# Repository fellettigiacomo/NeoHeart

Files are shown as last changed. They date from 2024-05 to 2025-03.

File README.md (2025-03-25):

# NeoHeart - Revision 2.2🎉
Hardware and Software design for an Open Source ATtiny816-based heart shaped PCB with Addressable LEDs.
<br><br>board-render
## Project sponsor: PCBWay
Thanks to [PCBWay](https://www.pcbway.com/) for sponsoring this open-source project. Check out the sponsorship section below to learn more about their support.

## Features

- **Microcontroller**: ATtiny816
- **LEDs**: 25 SK6805-MINIJ Addressable RGB LEDs
- **Power**: 3V CR2032 battery
- **Programming**: UPDI programming interface
- **Software**: Built using Adafruit's Neopixel library, featuring 10 built-in animations and efficient power management
- **Additional Features**:
  - Low current consumption design
  - Integrated MOSFET for powering down LEDs to save power
  - Additional digital/analog exposed GPIO to hack your NeoHeart in unexpected ways
  
## 2.2 Upgrades

- **Efficient power design**: the TPS61240 boost converter has been fully redesigned—now controlled by the MCU via the Enable pin (no more external MOSFET). Improved input stability with additional capacitors, removed feedback resistors for better overall efficiency.
- **Extended Battery Life**: ultra-low 0.14 µA quiescent current enables over 10 years of idle operation and supports 1000+ button presses on a single CR2032 cell.
- **Enhanced ATiny816 Stability**: added decoupling capacitors to ensure reliable and noise-free microcontroller performance.
- **Upgraded Battery Holder**: replaced the CR2032 holder with a more robust and durable version to prevent mechanical failure.
- **Improved Grounding**: added a dedicated ground plane for better signal integrity and reduced noise.
    
## Getting Started

To get started with NeoHeart, follow these steps:
1. **Assembly**: 
   - If you didn't assemble the back using economic PCBA (which I recommend), solder the [battery holder](https://aliexpress.com/item/1005005506756152.html).
2. **Powering the Board**:
   - Insert a CR2032 battery into the battery holder, ensuring the positive side of the battery matches the positive marking on the board. Alternatively, you can also power the board with the 5V and GND headers
3. **Installing Software**:
   - Install the Legacy version of the [Arduino IDE](https://www.arduino.cc/en/software) (otherwise you will get the *a programmer is required to upload* error) or [PlatformIO](https://platformio.org/platformio-ide)
   - Install the Adafruit NeoPixel library.
4. **Connecting the Programmer**:
   - Connect your UPDI programmer to the UPDI header on your NeoHeart board. If using an Arduino or any other serial adapter that supports JTAG, follow the instructions provided [here](https://github.com/ElTangas/jtag2updi).
5. **Uploading the Firmware**:
   - Open the firmware sketch provided in the repository.
   - Select the correct board and port in your IDE of choice.
   - Click on the upload button to flash your NeoHeart.
6. **Enjoy**:
   - Once programmed, your NeoHeart will be ready to go. Just hit the button and watch those LEDs light up!

## Manufacturing
Without including taxes, shipping and with current parts pricing 5 assembled boards (front only, having to solder the battery holder yourself) will cost around 52 USD dollars, so around 10 bucks a board.
<br><br>You can find all the files for production in the *releases* tab of this repository.
<br>All parts should available and ready to order, otherwise, feel free to send me a pull request.

## Contributing
Any contribution aimed to improving the software or the hardware of NeoHeart are very welcomed. 
Please feel free to fork this repo, make changes, and submit pull requests.

## PCBWay
I've been able to prototype the latest NeoHeart Release thanks to PCBWay that reached out to sponsor this project.
<br> You can see a photo of the boards that PCBWay sent me down here, you can also watch my unboxing video [here](https://youtu.be/b7MC2HfKiS8)
<br><br>pcbway-boards
### Why PCBWay?
- **Quality and Reliability**: PCBWay's PCBs meet the highest standards of quality and reliability, they are also capable of meeting the technical demands of any project, from simple projects like mine to very complicated projects.
- **Customization and Flexibility**: They offer extensive customization options, allowing board designers to tailor their PCBs precisely to their project's needs.
- **Community Support**: PCBWay is a strong supporter of open-source projects, offering sponsorships and discounts to help bring these community-beneficial projects to life. Their commitment to the open-source community makes them a particularly good match for community-driven initiatives.
- **Rapid Prototyping**: Time is very important in project development, and PCBWay’s rapid prototyping service allows for quick turnarounds without sacrificing quality.

### My Experience with PCBWay
It's been fantastic: our collaboration not only consisted in receiving high-quality PCBs (with PCBA), experiencing a seamless process facilitated by their expert team, from selecting the right components to checking for errors. 
<br>I've also received photos of the assembled boards before shipping to ensure everything was perfect!.
<br><br>Despite different time zones, the response time from their support team was impressive, which I found incredibly helpful.
<br><br>As I said before, I think it's fantastic that big companies like PCBWay are committed to the open-source community, helping students worldwide bring their projects to life. <b> Thanks again PCBWay!! </b>

## License
CERN Open Hardware License - Strongly Reciprocal (CERN-OHL-S)

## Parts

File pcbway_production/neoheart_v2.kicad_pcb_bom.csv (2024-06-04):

designator | quantity | value | pack | mpn | mount_type
BT1 | 1 | Battery | BatteryHolder_Keystone_1060_1x2032 |  | smt
C2 | 1 | 100nF | C_0402_1005Metric_Pad0.74x0.62mm_HandSolder |  | smt
C3, C4 | 2 | 22μF | C_0603_1608Metric |  | smt
D1, D10, D11, D12, D13, D14, D15, D16, D17, D18, D19, D2, D20, D21, D22, D23, D24, D25, D3, D4, D5, D6, D7, D8, D9 | 25 | SK6805 | LED_SK6805_PLCC4_2.4x2.7mm_P1.3mm |  | smt
J1 | 1 | Conn_01x03 | PinHeader_1x03_P2.54mm_Vertical |  | tht
L1 | 1 | MLP2012V4R7MT0S1 | L_0805_2012Metric |  | smt
MCU1 | 1 | ATtiny816-MNR | VQFN-20-1EP_3x3mm_P0.4mm_EP1.7x1.7mm |  | smt
Q1 | 1 | A1SHB | SOT95P237X112-3N |  | smt
Q2 | 1 | BSS138 | SOT95P237X112-3N |  | smt
R1 | 1 | 1K | R_0402_1005Metric_Pad0.72x0.64mm_HandSolder |  | smt
R2 | 1 | 180kΩ | R_0805_2012Metric |  | smt
R3 | 1 | 1,5MΩ | R_0603_1608Metric |  | smt
R4, R5 | 2 | 10K | R_0402_1005Metric_Pad0.72x0.64mm_HandSolder |  | smt
SW-ANIM1 | 1 | TS-1187A-B-A-B | SW_Push_1P1T_XKB_TS-1187A |  | smt
TP1, TP2, TP4 | 3 | PC3 | TestPoint_Pad_D1.0mm |  | tht
U2 | 1 | TPS61240TDRVRQ1 | SON65P200X200X80-7N |  | smt

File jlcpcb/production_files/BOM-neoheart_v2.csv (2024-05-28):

Comment | Designator | Footprint | LCSC
1K | R1 | R_0402_1005Metric_Pad0.72x0.64mm_HandSolder | C11702
100nF | C2 | C_0402_1005Metric_Pad0.74x0.62mm_HandSolder | C1525
180kΩ | R2 | R_0805_2012Metric | C17501
TPS61240TDRVRQ1 | U2 | SON65P200X200X80-7N | C2862536
SK6805 | D1,D10,D11,D12,D13,D14,D15,D16,D17,D18,D19,D2,D20,D21,D22,D23,D24,D25,D3,D4,D5,D6,D7,D8,D9 | LED_SK6805_PLCC4_2.4x2.7mm_P1.3mm | C2909056
A1SHB | Q1 | SOT95P237X112-3N | C2926133
MLP2012V4R7MT0S1 | L1 | L_0805_2012Metric | C383376
1,5MΩ | R3 | R_0603_1608Metric | C4172
22μF | C3,C4 | C_0603_1608Metric | C59461
Conn_01x03 | J1 | PinHeader_1x03_P2.54mm_Vertical
PC3 | PC3 | TestPoint_Pad_D1.0mm

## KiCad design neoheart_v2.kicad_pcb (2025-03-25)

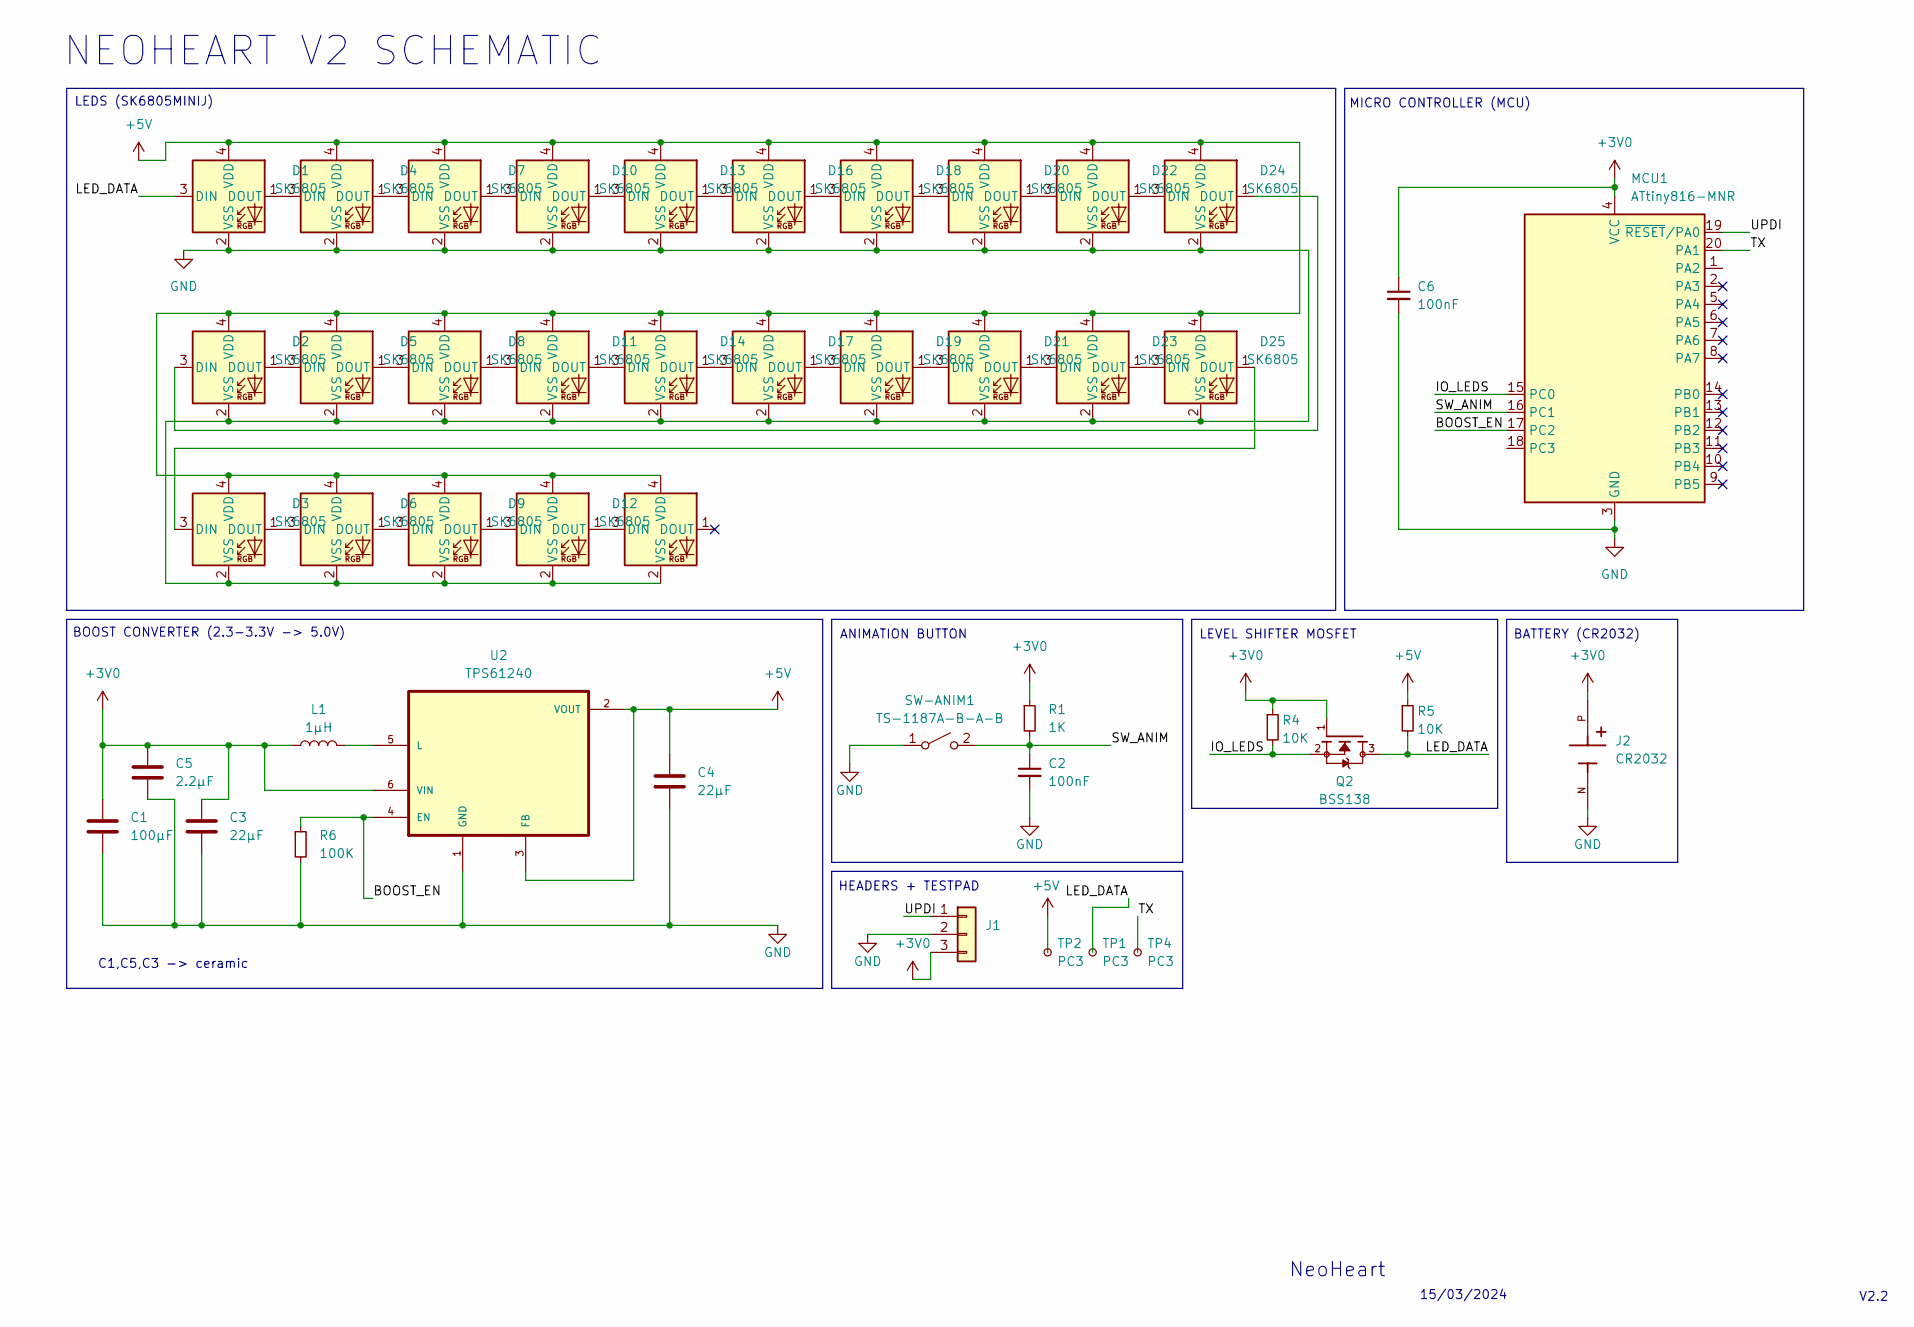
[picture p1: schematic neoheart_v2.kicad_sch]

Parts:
C1: 100µF; C_1210_3225Metric_Pad1.33x2.70mm_HandSolder
C2: 100nF; C_0402_1005Metric_Pad0.74x0.62mm_HandSolder
C3: 22μF; C_0805_2012Metric_Pad1.18x1.45mm_HandSolder
C4: 22μF; C_0603_1608Metric_Pad1.08x0.95mm_HandSolder
C5: 2.2µF; C_0805_2012Metric_Pad1.18x1.45mm_HandSolder
C6: 100nF; C_0603_1608Metric
D1, D2, D3, D4, D5, D6, D7, D8, D9, D10, D11, D12, D13, D14, D15, D16, D17, D18, D19, D20, D21, D22, D23, D24, D25: SK6805; LED_SK6805_PLCC4_2.4x2.7mm_P1.3mm
J1: Conn_01x03; PinHeader_1x03_P2.54mm_Vertical
J2: CR2032; HARWIN_S8421-45R; PARTREV 7
L1: 1μH; L_0805_2012Metric_Pad1.05x1.20mm_HandSolder
MCU1: ATtiny816-MNR; VQFN-20-1EP_3x3mm_P0.4mm_EP1.7x1.7mm
Q2: BSS138; SOT95P237X112-3N; PARTREV April 24, 2014
R1: 1K; R_0402_1005Metric_Pad0.72x0.64mm_HandSolder
R4, R5: 10K; R_0402_1005Metric_Pad0.72x0.64mm_HandSolder
R6: 100K; R_0805_2012Metric_Pad1.20x1.40mm_HandSolder
SW-ANIM1: TS-1187A-B-A-B; SW_Push_1P1T_XKB_TS-1187A
TP1, TP2, TP4: PC3; TestPoint_Pad_D2.0mm
U2: TPS61240; SON65P200X200X80-7N

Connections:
+3V0: C1.1, C3.1, C5.1, C6.1, J1.3, J2.P, L1.1, MCU1.4 (VCC), Q2.1, R1.1, R4.1, U2.6 (VIN)
+5V: C4.1, D1.4 (VDD), D2.4 (VDD), D3.4 (VDD), D4.4 (VDD), D5.4 (VDD), D6.4 (VDD), D7.4 (VDD), D8.4 (VDD), D9.4 (VDD), D10.4 (VDD), D11.4 (VDD), D12.4 (VDD), D13.4 (VDD), D14.4 (VDD), D15.4 (VDD), D16.4 (VDD), D17.4 (VDD), D18.4 (VDD), D19.4 (VDD), D20.4 (VDD), D21.4 (VDD), D22.4 (VDD), D23.4 (VDD), D24.4 (VDD), D25.4 (VDD), R5.1, TP2.1, U2.2 (VOUT), U2.3 (FB)
/BOOST_EN: MCU1.17 (PC2), R6.1, U2.4 (EN)
/IO_LEDS: MCU1.15 (PC0), Q2.2, R4.2
/LED_DATA: D1.3 (DIN), Q2.3, R5.2, TP1.1
/SW_ANIM: C2.1, MCU1.16 (PC1), R1.2, SW-ANIM1.2 (B)
/TX: MCU1.20 (PA1), TP4.1
/UPDI: J1.1, MCU1.19 (~RESET/PA0)
GND: C1.2, C2.2, C3.2, C4.2, C5.2, C6.2, D1.2 (VSS), D2.2 (VSS), D3.2 (VSS), D4.2 (VSS), D5.2 (VSS), D6.2 (VSS), D7.2 (VSS), D8.2 (VSS), D9.2 (VSS), D10.2 (VSS), D11.2 (VSS), D12.2 (VSS), D13.2 (VSS), D14.2 (VSS), D15.2 (VSS), D16.2 (VSS), D17.2 (VSS), D18.2 (VSS), D19.2 (VSS), D20.2 (VSS), D21.2 (VSS), D22.2 (VSS), D23.2 (VSS), D24.2 (VSS), D25.2 (VSS), J1.2, J2.N, MCU1.3 (GND), MCU1.21 (GND), R6.2, SW-ANIM1.1 (A), U2.1 (GND)
unnamed: D1.1 (DOUT), D4.3 (DIN)
unnamed: D2.3 (DIN), D24.1 (DOUT)
unnamed: D2.1 (DOUT), D5.3 (DIN)
unnamed: D3.1 (DOUT), D6.3 (DIN)
unnamed: D4.1 (DOUT), D7.3 (DIN)
unnamed: D5.1 (DOUT), D8.3 (DIN)
unnamed: D6.1 (DOUT), D9.3 (DIN)
unnamed: D7.1 (DOUT), D10.3 (DIN)
unnamed: D10.1 (DOUT), D13.3 (DIN)
unnamed: D8.1 (DOUT), D11.3 (DIN)
unnamed: D11.1 (DOUT), D14.3 (DIN)
unnamed: D9.1 (DOUT), D12.3 (DIN)
unnamed: D12.1 (DOUT), D15.3 (DIN)
unnamed: D13.1 (DOUT), D16.3 (DIN)
unnamed: D14.1 (DOUT), D17.3 (DIN)
unnamed: D16.1 (DOUT), D18.3 (DIN)
unnamed: D17.1 (DOUT), D19.3 (DIN)
unnamed: D18.1 (DOUT), D20.3 (DIN)
unnamed: D19.1 (DOUT), D21.3 (DIN)
unnamed: D20.1 (DOUT), D22.3 (DIN)
unnamed: D21.1 (DOUT), D23.3 (DIN)
unnamed: D22.1 (DOUT), D24.3 (DIN)
unnamed: D23.1 (DOUT), D25.3 (DIN)
unnamed: D3.3 (DIN), D25.1 (DOUT)
unnamed: L1.2, U2.5 (L)

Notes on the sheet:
MICRO CONTROLLER (MCU)
NEOHEART V2 SCHEMATIC
BATTERY (CR2032)
C1,C5,C3 -> ceramic
NeoHeart
HEADERS + TESTPAD
ANIMATION BUTTON
BOOST CONVERTER (2.3-3.3V -> 5.0V)
15/03/2024
LEDS (SK6805MINIJ)
V2.2
LEVEL SHIFTER MOSFET

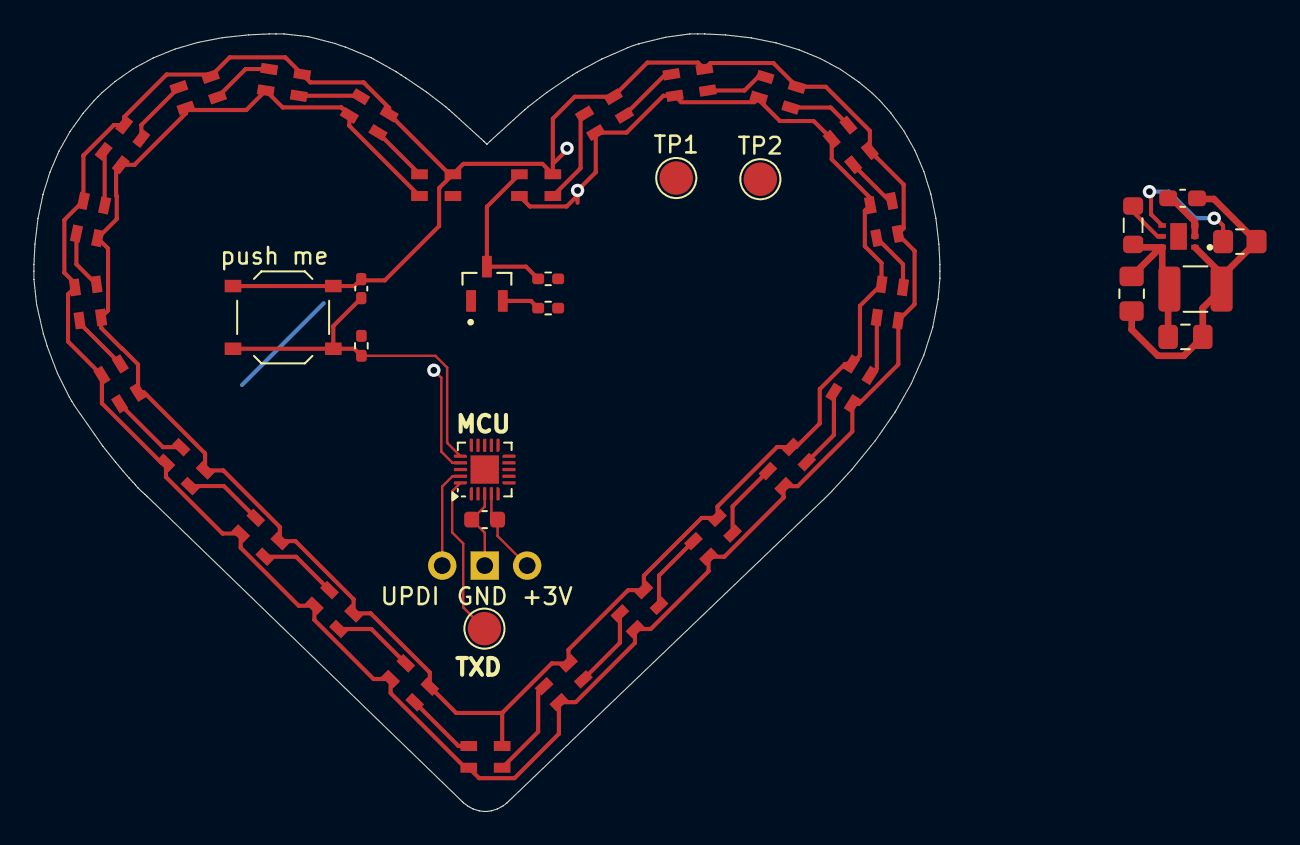
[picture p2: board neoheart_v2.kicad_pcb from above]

Board: 2 copper layers, 54.2 x 46.5 mm, 45 parts (1 on the bottom side), 34 nets.

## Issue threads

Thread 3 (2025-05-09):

Via-In-Pad

rtrevinnoc, 2025-05-09:
Hello! I sent the files for production to PCBWay and they pointed out that there are via-in-pads used in the design, for example on the GND connections for the LEDs. They sent me an email saying this would significantly increase the cost to over $100. Is this the intended way to reproduce the design, or am I doing something wrong?

Thank you beforehand

fellettigiacomo, 2025-05-09:
Hi Roberto, first of all, thanks for trying to manufacture my project!
I've produced the latest revision (2.2) of NeoHeart with PCBWay and I had no issues with the vias in the LEDs pads; however, is it possible to move them to another place close to the LEDs.
Just a quick note, the current release still has some issues with the low CR2032 current causing glitches, so the board **isn't really ready for production yet**, sadly :(
I'm currently working on a fix in my spare time, but I’m honestly a bit stuck ATM. I was thinking about using a LiPo battery, but that would increase the BOM price A LOT.

I'll let you know when the board will be ready for production.
Have an amazing day!

rtrevinnoc, 2025-05-09:
Hi Jack!

Thank you for your very quick reply! It is a very fun project, thank you for sharing it.
Very well then, I think I will send it to manufacture just to try it out then, I'd like to play with the ATTiny anyway.
About your note on the low current, I will try to help and then I would send a pull request. I'm not very experienced on the topic as my background is purely on software but I will look around for a properly-sized battery replacement that can provide enough current and share what I find.

Have a good day, and thanks for your help once again

fellettigiacomo, 2025-05-09:
I think the key is in using big capacitors to allow current bumps or to change the boost converter (which converts from 2-3V to the 5V required by the SK6805 LEDs) design.
At the moment, I’m a bit lost tbh.
If you continue with production, be aware that while powered with a CR2032, the board may have glitches or sometimes it might not even work, requiring a hard reset. With an external 3V power supply it works perfectly.
I was thinking if you want, I could ship one of my NeoHearts v2.2 since I don't need five of them. Let me know, and in case, feel free to reach out at hello@jack0217.dev.

Have a nice day and thanks for your kind words about the project :)

Closed 2025-05-12.

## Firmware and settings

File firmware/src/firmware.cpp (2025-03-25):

#include "firmware.h"

#ifdef __AVR__
#include <avr/interrupt.h>
#include <avr/power.h>
#include <avr/wdt.h>
#include <avr/sleep.h>
#endif

#define BTN PIN_PC1
#define MOSFET PIN_PC2

using namespace neoheart;
void enableSleep();
void softwareReset();
void runRandomAnim();
void disableSleep();

void setup() {
    // init leds
    initLeds();
    // clear strip from previous animations
    clearStrip();
    // init io
    pinMode(BTN, INPUT_PULLUP);
    pinMode(MOSFET, OUTPUT);
    // init random seed
    randomSeed(analogRead(PIN_PA2));
    // attach to interrupt
    attachInterrupt(digitalPinToInterrupt(BTN), softwareReset, FALLING);
    runRandomAnim();
}

void loop() {
    // nothing to do here
}

void runRandomAnim(){
    digitalWrite(MOSFET, HIGH);
    void (*animations[])() = {heartbeat, bottomup, theatherFill, bounce, incrementalFill, chase, colorWipe, rainbow, theaterChaseRainbow};
    int randomIndex = random(sizeof(animations) / sizeof(animations[0]));
    animations[randomIndex]();
    digitalWrite(MOSFET, LOW);
    detachInterrupt(digitalPinToInterrupt(BTN));
    attachInterrupt(digitalPinToInterrupt(BTN), disableSleep, CHANGE);
    enableSleep();
}

void softwareReset() {
    // clear interrupts
    cli();
    // write in the watchdog control register
    _PROTECTED_WRITE(WDT.CTRLA, WDT_PERIOD_8CLK_gc | WDT_WINDOW_OFF_gc);
    // wait for the watchdog to reset the device
    while (1);
}

void enableSleep() {
    sleep_enable();
    set_sleep_mode(SLEEP_MODE_PWR_DOWN);  
    sleep_cpu();
}

void disableSleep() {
    sleep_disable();
    softwareReset();
}

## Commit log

2024-05-06 uploaded hardware
    uploaded final version of the board with production files and library for 3D models, footprints and symbols.
    [bom.csv, designators.csv, neoheart_v2.kicad_pcb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]
2024-05-08 deleted neoheart_v2.kicad_prl
2024-05-08 updated schematic
2024-05-08 uploaded hardware
    [neoheart_v2.kicad_pcb]
2024-05-08 updated neoheart_v2.kicad_sch
    [neoheart_v2.kicad_sch]
2024-05-28 updated firmware: mosfet, sleep, bugfixes
    [firmware.cpp]
2024-05-28 added board render, cleanup, new production files
    [BOM-neoheart_v2.csv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]
2024-05-29 Fix glitches by disabling/enabling interrupts
2024-05-31 unfinished - revision 2.1
    [neoheart_v2.kicad_pcb, neoheart_v2.kicad_sch]
2024-05-31 fixed @depau's battery orientation trigger
    [neoheart_v2.kicad_sch]
2024-06-02 board revision 2.1
    [neoheart_v2.kicad_pcb, neoheart_v2.kicad_sch]
2024-06-02 updated silkscreen text
    [neoheart_v2.kicad_pcb]
2024-06-04 revision 2.1, pcbway production files
    [neoheart_v2.kicad_pcb, neoheart_v2.kicad_pcb_bom.csv, neoheart_v2.kicad_pcb_positions.csv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]
2024-06-11 add 3d models, new board render
    [neoheart_v2.kicad_pcb]
2025-03-25 2.2: update schematic, new boost converter design, hardware optimizations
    [neoheart_v2.kicad_pcb, neoheart_v2.kicad_sch]
